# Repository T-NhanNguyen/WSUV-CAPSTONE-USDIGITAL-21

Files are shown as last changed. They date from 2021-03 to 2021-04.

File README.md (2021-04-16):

# WSUV-CAPSTONE-USDIGITAL-21
 Senior capstone project for WSUV class of 2021
 
Critical problems with the current PCB design:
	There is an accidental short between RO pin of LTC485 and one of the button that I've overlooked. This means that one button would just be unusable

	The debugging LEDs are soldered in the wrong orientation. I didn't expect the LED to be this small

	Q1 power footprint is incorrect (which we've already addressed)

	Analog pin on the chip was not utilized for the Analog encoder port. (There are pin headers that allow us to connect it to another pin, but the Diodes won't be useable).

	AREF is shorted to ground, which prevents us from using ADC functionality of the MCU

	The dimensions of the LCD displays are wrong

	The wiring for the quadrature encoders aren't consistent

	This prototype uses a lot of 32 bit data types, however, this is a 16 bit processor, performances and memmory will be affected.

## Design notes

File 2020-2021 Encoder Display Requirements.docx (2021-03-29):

2020-2021 WSU Capstone Project

Encoder Display Interface – Requirements and Notes

V 1.1

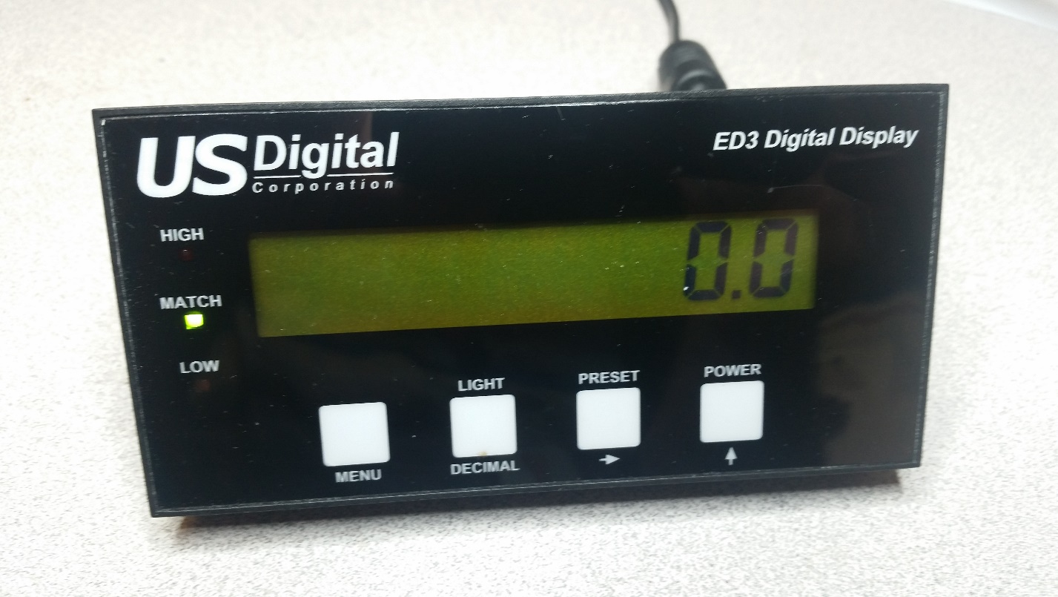
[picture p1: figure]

Background

The goal of this project is to design new electronic hardware to upgrade our existing ED3 Digital Display device. Our existing product (pictured above) displays limited information on its 8-character, 7-segment display and it is difficult for a user to configure using the 4-button interface. It is also limited to one quadrature or PWM encoder input. For reference, the data sheet for this product can be found at: https://www.usdigital.com/products/accessories/digital-displays/ED3 .

The newly designed hardware will allow device information to be displayed from all the US Digital encoder products. It will display information for up to two simultaneous encoder inputs. It will support quadrature, Step/Direction, PWM, RS232, RS485, SEI and analog encoder inputs. The display unit will be configured using a PC GUI application and parameters will be communicated over a USB interface. The display will also be enhanced to a multi-line alpha-numeric type.

Hardware Requirements

1. It is highly desired that the new electronic hardware fit into the existing ED3 product housing. Here are the dimensions of the current housing:

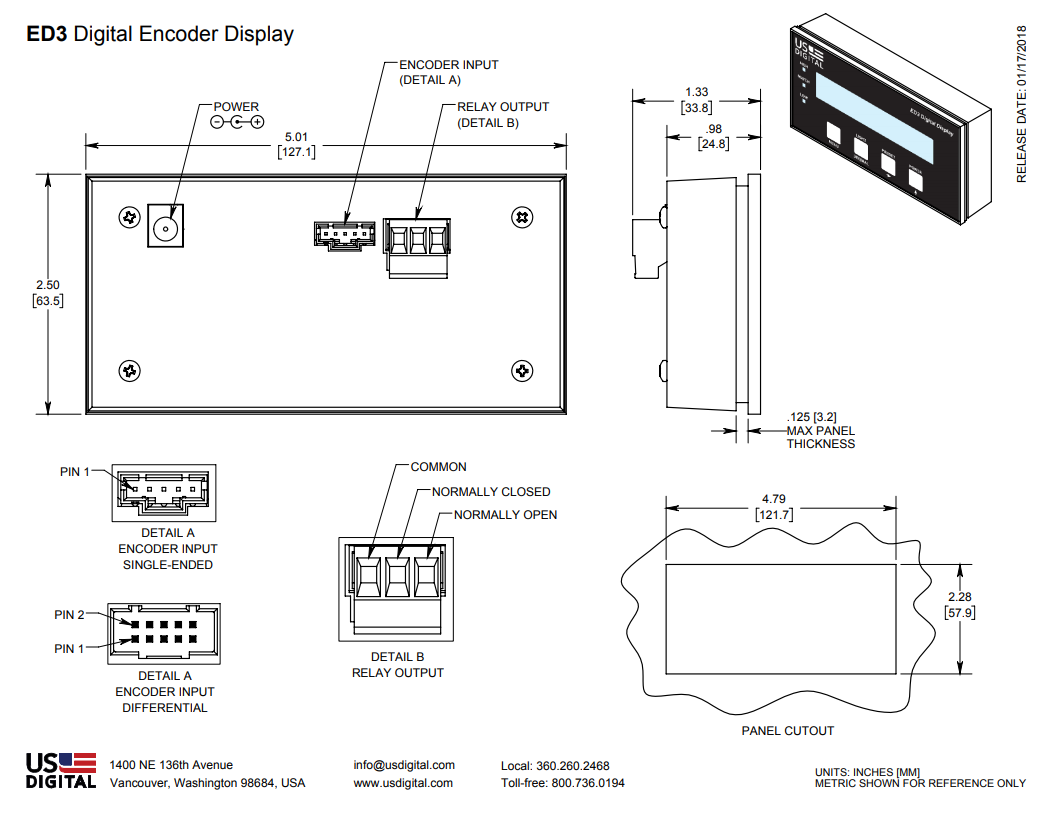
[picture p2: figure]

The connectors in the diagram above are for our incremental and PWM encoder products. We will be adding additional connectors for our currently unsupported products.

2. The display unit will have at least a two-line alpha-numeric LCD display with backlight. This can be an LCD module or a discrete LCD. A module, using an integrated control unit, may be easier to develop since it has the display driver built in.
3. Four momentary switches will allow for user control during standalone operation. Switch PN: PTS645SL70-2LFS
4. The display unit will operate from USB power when connected to a PC or operate standalone from an external 12V DC power source. Note: some of the encoders will require that the 12V source be connected. The external power connection will use a 2.1mm diameter center post power jack. This will be compatible with our existing 12V wall power modules. Suggested PN: PJ-044A
5. A USB connection will provide power for the display and a serial port connection to a PC. The PC will send operational parameters and user inputs to the display unit; it will also be able to read data from the display unit. (Note: we have used FTDI devices for USB interfaces in some of our other products; FTDI website: https://www.ftdichip.com . Suggested USB connector PNs: UJ2-AV-2-SMT-TR or 1734517-1
6. Use a Microchip 16-bit PIC microcontroller. It has useful built-in features such as:
- 12-bit A/D
- Multiple UART ports
- Multiple SPI ports
- Quadrature decoder with index (need at least a 16-bit quadrature counter)
- Possibly a USB port (slave mode)
- Probably this project will require >= 128 KB program memory
- Internal non-volatile memory for user parameter storage

At a minimum, enough microcontroller firmware will be written to demonstrate the functionality of the electronic hardware. Write all firmware in C language.

7. The display unit will have at least 256 bytes of non-volatile memory for storing user configuration information. This memory could be contained within the microcontroller.
8. The following encoder inputs will be supported:
- Capability for two Differential and two single-ended quadrature inputs with index. Connector: 5-pin locking; PN: 5-103639-4 (single ended); connector: 10-pin locking; PN: 15477510 (differential).
- Single-ended step/direction inputs. Connector: 5-pin locking; PN: 5-103639-4
- 12-bit PWM with 250 Hz to 2kHz period. Connector: 5-pin locking; PN: 5-103639-4
- RS232/RS485 (bidirectional communication) Shared Connector: 5-pin M12; PN: 284740. Only available when using external 12V supply.
- SEI bus interface (see SEI definition at: https://www.usdigital.com/support/resources/reference/user-guides/sei-serial-encoder-interface-bus ) Connector: RJ11 Modular Jack; PN: MTJ-663X1. Only available when using external 12V supply.
- 12-bit analog input, 0 – 5V. Connector: 5-pin locking; PN: 5-103639-4
9. A switching type power supply voltage regulator will be used to generate the needed voltages on board. 5V will be needed to power some of the attached encoder units. The 5V supply should be capable of supplying 150 mA of current to external 5V encoders.
10. An open-drain output FET transistor will be provided to switch external circuitry. It will be capable of switching 1 A of current (max) and 30V max Vds. Driven directly from microcontroller.
11. All components will be surface mount with a few exceptions (Possibly the LCD display, switches, USB connector and RJ11 Modular Jack)
12. All components will be readily available from DigiKey (www.digikey.com) or Mouser (www.mouser.com). All components must be compliant with RoHS and REACH standards; we will help with this.
13. PCB design will be a two-sided board, FR4 material, that is 0.063” thick. Suggest using Altium CircuitMaker Schematic/PCB layout tool (see design tools section below).

System Block Diagram

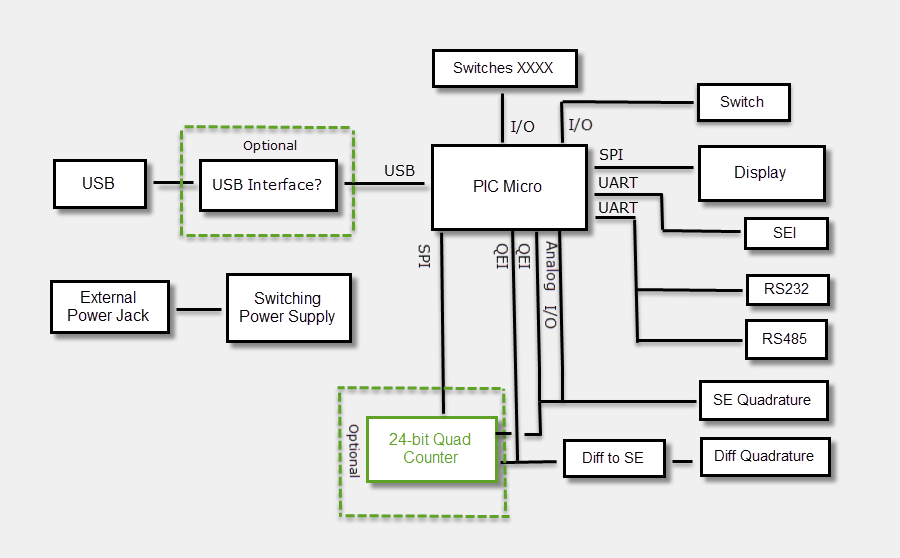
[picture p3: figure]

Connector Pinouts

1. Single-ended (5-pin) and differential (10-pin) encoder inputs.

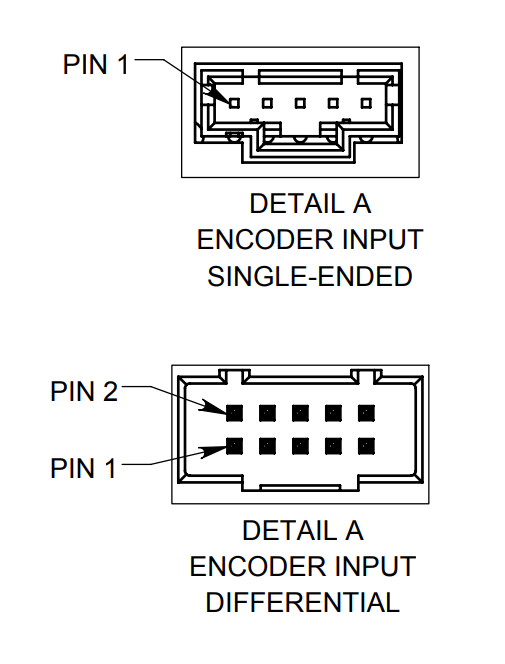
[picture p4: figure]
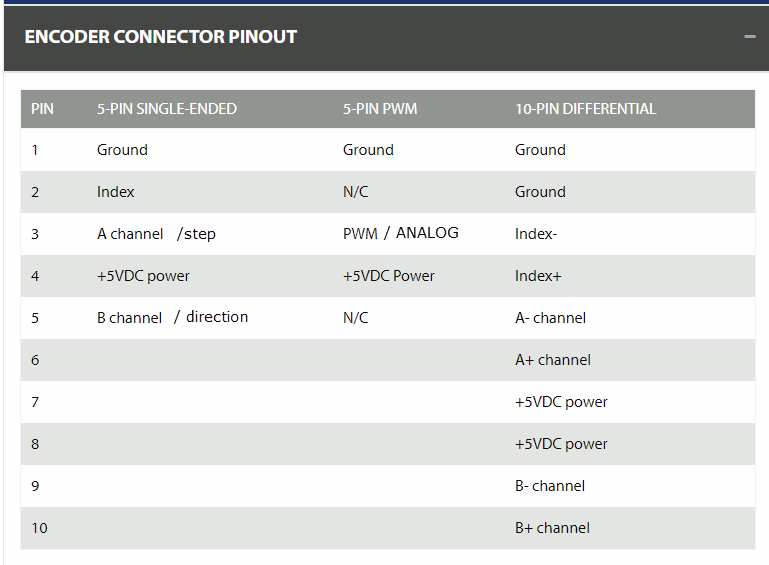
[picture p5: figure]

The single-ended quadrature encoder, step/direction encoder, PWM encoder and Analog encoder inputs will share the same 5-pin connector. The 10-pin connector will only be used for the differential encoder input. We will limit to two of these encoder connections that can either be stuffed with a 5-pin connector or a 10-pin connector.

2. RS232/RS485

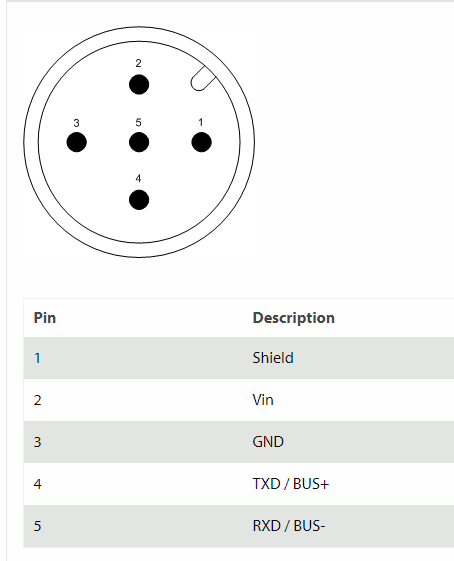
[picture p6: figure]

The RS232 and RS485 interface will share the same connector. Vin will be 12V

3. SEI

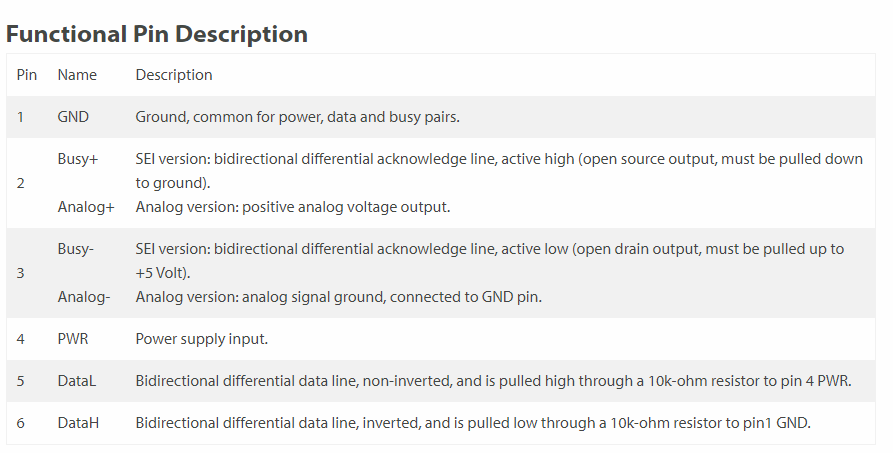
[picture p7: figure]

PWR will be 12V

Suggested Design Tools and Web Sites

1. Free schematic and PCB Layout Tool that generates files that are compatible with our currently used Altium Designer PCB layout tool: Altium CircuitMaker https://circuitmaker.com/
2. Analog Simulation Tool: LTSpice https://www.analog.com/en/design-center/design-tools-and-calculators/ltspice-simulator.html# . Useful for switching voltage regulator design.
3. Electronic component part Sources: www.DigiKey.com , www.Mouser.com
4. Some standard component schematic symbols and PCB footprints: https://www.ultralibrarian.com/ . Or, you can make the symbols from withing CircuitMaker.
5. You will need an in-circuit firmware design tool. Free software is available from Microchip. We can supply a Microchip PICkit-3 programmer dongle if needed.

Project Challenges

1. On-board switching power supply regulator design. LTSpice analog simulation tool may assist in this design.
2. Learning PCB layout techniques. I can help with this.
3. Switching between RS485 and RS232 communication on one shared connector.
4. Component selections. Also, choosing the best PIC microcontroller for the project.
5. Making all if the electronic circuitry fit on the desired PCB size. We may have to increase the PCB size if all the components will not fit, TBD

Other

1. Email a copy of your status reports to Allen.Harstine@usdigital.com
2. Please contact me (Allen Harstine) if you have any problems with the design requirements or other questions. Email: Allen.Harstine@usdigital.com .
3. We should review each milestone step below as you complete these steps:
- Product requirements review
- Product block diagram or project plan review
- Parts selection review
- Schematic review
- Test firmware review
- PCB pre-layout review
- PCB post-layout review
4. USD can help with circuit board fabrication (soldering). Some of the packages will require reflow soldering since the conductors my be on the bottom of the component package.
5. US Digital product website: www.usdigital.com

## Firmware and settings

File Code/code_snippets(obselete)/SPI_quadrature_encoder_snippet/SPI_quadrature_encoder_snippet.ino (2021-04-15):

#include <SPI.h>
#include <util/delay.h>            // Delay functions
#include <SoftwareSerial.h>        // Serial Library
#include "Arduino.h"               // Arduino

const int cs_1 = 6;
const int cs_2 = 12;

volatile long int test_read1;
volatile long int test_read2;

/*
SPCR configuration
CPOL = 0, CPHA = 0, Mode0
DORD = 0, MSB first
MSTR = 1, Master
SPE = 1, SPI enabled
SCK frequency = fosc/4
*/

//Count modes
#define NQUAD 0x00 //non-quadrature mode
#define QUADRX1 0x01 //X1 quadrature mode
#define QUADRX2 0x02 //X2 quadrature mode
#define QUADRX4 0x03 //X4 quadrature mode
//Running modes
#define FREE_RUN 0x00
#define SINGE_CYCLE 0x04
#define RANGE_LIMIT 0x08
#define MODULO_N 0x0C
//Index modes
#define DISABLE_INDX 0x00 //index_disabled
#define INDX_LOADC 0x10 //index_load_CNTR
#define INDX_RESETC 0x20 //index_rest_CNTR
#define INDX_LOADO 0x30 //index_load_OL
#define ASYNCH_INDX 0x00 //asynchronous index
#define SYNCH_INDX 0x80 //synchronous index
//Clock filter modes
#define FILTER_1 0x00 //filter clock frequncy division factor 1
#define FILTER_2 0x80 //filter clock frequncy division factor 2
/* **MDR1 configuration data; any of these***
 ***data segments can be ORed together***/
//Flag modes
#define NO_FLAGS 0x00 //all flags disabled
#define IDX_FLAG 0x10 //IDX flag
#define CMP_FLAG 0x20 //CMP flag
#define BW_FLAG 0x40 //BW flag
#define CY_FLAG 0x80 //CY flag
//1 to 4 bytes data-width
#define BYTE_4 0x00 //four byte mode
#define BYTE_3 0x01 //three byte mode
#define BYTE_2 0x02 //two byte mode
#define BYTE_1 0x03 //one byte mode
//Enable/disable counter
#define EN_CNTR 0x00 //counting enabled
#define DIS_CNTR 0x04 //counting disabled

/* LS7366R op-code list */
#define CLR_MDR0 0x08
#define CLR_MDR1 0x10
#define CLR_CNTR 0x20
#define CLR_STR 0x30
#define READ_MDR0 0x48
#define READ_MDR1 0x50

#define READ_CNTR 0x60
#define READ_OTR 0x68
#define READ_STR 0x70
#define WRITE_MDR1 0x90
#define WRITE_MDR0 0x88
#define WRITE_DTR 0x98
#define LOAD_CNTR 0xE0
#define LOAD_OTR 0xE4

long int ls7366r_read_cntr(uint8_t device);

uint8_t ls7366r_recieve(uint8_t device, uint8_t op_code) {
  uint8_t data = 0;

  // Serial.print("opcode for read: "); Serial.println(op_code);
// *** slowing down the SPI clock to within capabilities of 7366 device (< 4MHz)
  SPI.beginTransaction(SPISettings(2000000, MSBFIRST, SPI_MODE0)); 
// *** switched enable/disable signal activation to within the SPI activation area, per SPI library recommendation
  digitalWrite(device, LOW);


  SPI.transfer(op_code);          // send out opcode
  data |= SPI.transfer(0);

  digitalWrite(device, HIGH);
  SPI.endTransaction();
  return data;
}

void ls7366r_write(uint8_t device, uint8_t op_code, uint8_t data) {
  
// *** SPI.beginTransaction(SPISettings(16000000, MSBFIRST, SPI_MODE0));
// *** slowing down the SPI clock to within capabilities of 7366 device (< 4MHz)
  SPI.beginTransaction(SPISettings(2000000, MSBFIRST, SPI_MODE0));

  // Serial.print("opcode and data for write: "); Serial.print(op_code);
  // Serial.print(" "); Serial.println(data);
// *** switched enable/disable signal activation to within the SPI activation area, per SPI library recommendation
  digitalWrite(device, LOW);

  SPI.transfer(op_code);            // required opcode
  SPI.transfer(data);

  digitalWrite(device, HIGH);
  SPI.endTransaction();
}

// "device" param corresponds to the CS pin assigned to the following device
void ls7366r_init(uint8_t device) {
  pinMode(device, OUTPUT);
  
  digitalWrite(device, HIGH); // cs default high
  
  // NOTE: LS7366R opperates faster than arduino
  SPI.begin();

  uint32_t mdr1_preset  = (BYTE_2|EN_CNTR);
  uint32_t mdr0_preset  = (FILTER_2|DISABLE_INDX|FREE_RUN|QUADRX4);
  
  // init encoder 1
  ls7366r_write(device, WRITE_MDR1, mdr1_preset);   // reg involving counters
  ls7366r_write(device, WRITE_MDR0, mdr0_preset);   // reg involve operation
  ls7366r_write(device, CLR_CNTR, 0);               // where encoder count is stored
  ls7366r_write(device, CLR_STR, 0);                // reg involves count related status information

  // verifying the decoder by comparing reg values
  if( (ls7366r_recieve(device, READ_MDR1) != mdr1_preset) ||
      (ls7366r_recieve(device, READ_MDR0) != mdr0_preset)  )
    {
        Serial.print(F("Failed validity check"));
        digitalWrite(A1, HIGH);
        while(1);
    }

  digitalWrite(device, HIGH); // cs default high
}

long int ls7366r_read_cntr(uint8_t device) {
  uint8_t byte_mode = ls7366r_recieve(device, READ_MDR1); 
  uint8_t data_length = 0;
  long int data = 0;
  byte_mode &= 3;       // determine which byte counter mode from LSB
  switch(byte_mode) {   // assign the length for read loop
    case 0:
      data_length = 4;
      break;
    case 1:
      data_length = 3;
      break;
    case 2:
      data_length = 2;
      break;
    case 3:
      data_length = 1;
      break;
  }

  SPI.beginTransaction(SPISettings(2000000, MSBFIRST, SPI_MODE0)); 
  digitalWrite(device, LOW);
  
  SPI.transfer(READ_CNTR);          // send out opcode
  
  // perform bit shifts while appending the next byte
  for(int i = 0; i < (data_length - 1); i++) {
    data |= SPI.transfer(0);
// *** changed bit shift from 4 to 8
    data <<= 8;
  }
  data |= SPI.transfer(0);

  digitalWrite(device, HIGH);
  SPI.endTransaction();
  
  return data;
}

void print_concatstr(char *sentence, int value) {
  Serial.print(sentence);
  Serial.print(" ");
  Serial.println(value);
}


void setup() {
  pinMode(A1, OUTPUT);  // debug_led
  digitalWrite(A1, LOW);
  Serial.begin(9600);   //open serial port at 9600 bps
  // delay(2000);
  ls7366r_init(cs_1);
  ls7366r_init(cs_2);
}

void loop() {
  test_read1 = ls7366r_read_cntr(cs_1);
  test_read2 = ls7366r_read_cntr(cs_2);
  print_concatstr("Read CNTR 1:", int(test_read1));
  print_concatstr("Read CNTR 2:", int(test_read2));

/*
  test_read1 = ls7366r_recieve(cs_1 ,READ_STR);
  test_read2 = ls7366r_recieve(cs_2 ,READ_STR);
  print_concatstr("READ_STR 1:", test_read1);
  print_concatstr("READ_STR 2:", test_read2);

  test_read1 = ls7366r_recieve(cs_1 ,READ_OTR);
  test_read2 = ls7366r_recieve(cs_2 ,READ_OTR);
  print_concatstr("READ_OTR 1:", test_read1);
  print_concatstr("READ_OTR 2:", test_read2);
*/

//  delay(1000);
}

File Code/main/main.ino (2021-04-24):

#include <SPI.h>
#include <Arduino.h>
#include <U8g2lib.h>

#ifndef LCDPINS
  #define REGSEL  4
  #define CS    5
#endif

#ifndef DECODE_CS
  #define CS1 6
  #define CS2 12
#endif

#ifndef PWM_PIN
  #define pwm_signal 2             //digital pin 11 did not work
#endif

U8G2_ST7565_NHD_C12864_F_4W_SW_SPI u8g2(U8G2_R0, SCK , MOSI, CS, REGSEL, U8X8_PIN_NONE);

static const int analog_pin = A3;
extern volatile long pwm_reading;

// display
void display_init();
void u8g2_prepare(void);
void display_all_screen(int dual_line_value, int single_line_value, int analog_value, int pwm_value);
int largest(int arr[], int n);

// quadrature encoder
long int ls7366r_read_cntr(uint8_t device);
uint8_t ls7366r_recieve(uint8_t device, uint8_t op_code);
void ls7366r_write(uint8_t device, uint8_t op_code, uint8_t data);
void ls7366r_init(uint8_t device);
long int ls7366r_read_cntr(uint8_t device);
void print_concatstr(char *sentence, int value);

// pwm decoder
void setup_pwm_decoder();
void rising_edge();
void falling_edge();

// analog decoder
void setup_analog_decoder(int pin);

void goto_to_homescreen() {
  u8g2.firstPage();
  u8g2_prepare();
  home_screen();
  u8g2.sendBuffer();
  while(1){
    if(!digitalRead(10) || !digitalRead(9)) {
      delay(500);
      break;
    }
  }
}

void setup() {
  Serial.begin(9600);
  // NOTE: LS7366R opperates faster than arduino
  SPI.begin();

  pinMode(10, INPUT);
  pinMode(9, INPUT);
  
  setup_pwm_decoder();
  setup_analog_decoder(analog_pin);
  
  ls7366r_init(CS1);
  ls7366r_init(CS2);

  SPI.end();        // this interfere with the display's api somehow?...
  display_init();
  
  goto_to_homescreen();
}

void loop() {
  SPI.begin();
  int analog_encoder = map(analogRead(analog_pin), 0, 670, 0, 100);
  int sing_line = ls7366r_read_cntr(CS1);
  int dual_line = ls7366r_read_cntr(CS2);
  int pwm_encoder = map(pwm_reading, 0, 1024, 0, 100);;
  SPI.end();

  u8g2.firstPage();
  u8g2_prepare();
  // display_all_screen(-1, -1, -1, -1);
  display_all_screen(dual_line, sing_line, analog_encoder, pwm_encoder);
  u8g2.sendBuffer();

  if(!digitalRead(10))
    goto_to_homescreen();
}

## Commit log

2021-04-13 all encoders displayed
2021-04-15 Linked encoder reading with tdisplay
2021-04-15 implemented the buttons
2021-04-17 pwm fix and readme
    [pwm_analog.ino]
2021-04-24 implemented button demo
